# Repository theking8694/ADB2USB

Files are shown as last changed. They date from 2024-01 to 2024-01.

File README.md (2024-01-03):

# ADB2USB
An Apple ADB to USB adapter for QMK using the ATMega32U2, featuring USB-C!
One of the projects I used as an intro to KiCad

Probably not the simplest, but follows what is said for the 32U2 datasheet.

Tested working, highly suggest a 32U2 with DFU bootloader flashed (DigiKey seems to have them preflashed)
Highly reccomend using hot air instead of an iron.

You can use the online QMK configurator firmware builder to produce a .hex that can be flashed using QMK Toolbox (Arduino will not see the DFU bootloader!)
(Or compile it locally and flash it however you want)

The CSV contains a BOM listing generated by KiCad,
parts I used are listed below:

GRM0335C1E200JA01D (20pF cap), 

CL05A105MQ5NNNC (1uF cap), 

USB4085-GF-A (USB C port), 

RMCF0805FT1K00 (1k resistor), 

WR06X220 JTL (22 resistor), 

ABLS-16.000MHZ-D-3-Y-T (16Mhz crystal), 

M50-3530342 (optinal ISP headers), 

PTS526 SM15 SMTR2 LFS (reset switch), 

RR0816P-512-D (5.1k resistor), 

WR06X103 JTL (10k resistor), 

CUI_MD-40SMK (S-video socket) (yes, S-video),

and, of course, an ATMega32U2(-A)

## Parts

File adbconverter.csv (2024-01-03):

Component Count: | 16
Ref | Qnty | Value | Cmp name | Footprint | Description | Vendor | DNP
C1, C2 | 2 | 20pF | C | Capacitor_SMD:C_0201_0603Metric_Pad0.64x0.40mm_HandSolder | Unpolarized capacitor
C3, C4 | 2 | 1uF | C | Capacitor_SMD:C_0402_1005Metric_Pad0.74x0.62mm_HandSolder | Unpolarized capacitor
J1 | 1 | AVR-ISP-6 | AVR-ISP-6 | Connector_PinHeader_1.27mm:PinHeader_2x03_P1.27mm_Vertical | Atmel 6-pin ISP connector
J2 | 1 | DIN-4 | MD-40SMK | adbconverter:CUI_MD-40SMK
P1 | 1 | USB C Receptacle 3.0 | USB_C_Receptacle_USB2.0 | Connector_USB:USB_C_Receptacle_GCT_USB4085 | USB 2.0-only Type-C Receptacle connector
R1, R2 | 2 | 5.1k | R_US | Resistor_SMD:R_0603_1608Metric_Pad0.98x0.95mm_HandSolder | Resistor, US symbol
R3 | 1 | 10k | R_US | Resistor_SMD:R_0603_1608Metric_Pad0.98x0.95mm_HandSolder | Resistor, US symbol
R_ADB1 | 1 | 1k | R_US | Resistor_SMD:R_0805_2012Metric_Pad1.20x1.40mm_HandSolder | Resistor, US symbol
R_D+1 | 1 | 22 | R_US | Resistor_SMD:R_0603_1608Metric_Pad0.98x0.95mm_HandSolder | Resistor, US symbol
R_D-1 | 1 | 22 | R_US | Resistor_SMD:R_0603_1608Metric_Pad0.98x0.95mm_HandSolder | Resistor, US symbol
SW1 | 1 | RESET | SW_Push | Button_Switch_SMD:SW_SPST_SKQG_WithStem | Push button switch, generic, two pins
U1 | 1 | ATmega32U2-A | ATmega32U2-A | Package_QFP:TQFP-32_7x7mm_P0.8mm | 16MHz, 32kB Flash, 1kB SRAM, 1kB EEPROM, TQFP-32
Y1 | 1 | Crystal | Crystal | Crystal:Crystal_SMD_HC49-SD | Two pin crystal

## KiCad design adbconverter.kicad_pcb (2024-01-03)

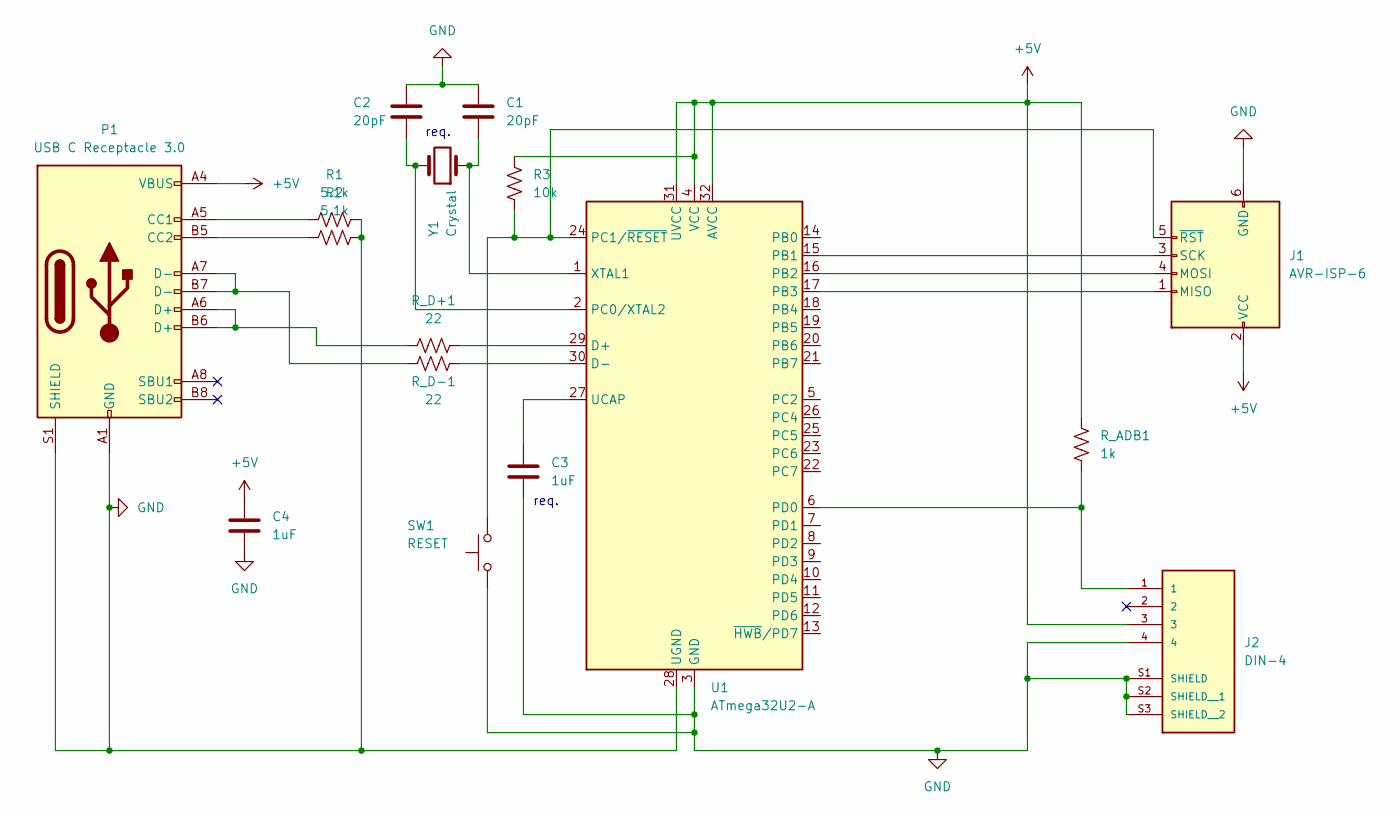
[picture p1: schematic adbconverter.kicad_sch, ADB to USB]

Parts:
C1, C2: 20pF; C_0201_0603Metric_Pad0.64x0.40mm_HandSolder
C3, C4: 1uF; C_0402_1005Metric_Pad0.74x0.62mm_HandSolder
J1: AVR-ISP-6; PinHeader_2x03_P1.27mm_Vertical
J2: DIN-4; CUI_MD-40SMK; PART_REV 1.02
P1: USB C Receptacle 3.0; USB_C_Receptacle_GCT_USB4085
R1, R2: 5.1k; R_0603_1608Metric_Pad0.98x0.95mm_HandSolder
R3: 10k; R_0603_1608Metric_Pad0.98x0.95mm_HandSolder
R_ADB1: 1k; R_0805_2012Metric_Pad1.20x1.40mm_HandSolder
R_D+1: 22; R_0603_1608Metric_Pad0.98x0.95mm_HandSolder
R_D-1: 22; R_0603_1608Metric_Pad0.98x0.95mm_HandSolder
SW1: RESET; SW_SPST_SKQG_WithStem
U1: ATmega32U2-A; TQFP-32_7x7mm_P0.8mm
Y1: Crystal; Crystal_SMD_HC49-SD

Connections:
+5V: C4.2, J1.2 (VCC), J2.3, P1.A4 (VBUS), P1.A9 (VBUS), P1.B4 (VBUS), P1.B9 (VBUS), R3.2, R_ADB1.2, U1.4 (VCC), U1.31 (UVCC), U1.32 (AVCC)
GND: C1.2, C2.2, C3.1, C4.1, J1.6 (GND), J2.4, J2.S1 (SHIELD), J2.S2 (SHIELD__1), J2.S3 (SHIELD__2), P1.A1 (GND), P1.A12 (GND), P1.B1 (GND), P1.B12 (GND), P1.S1 (SHIELD), R1.2, R2.2, SW1.1, U1.3 (GND), U1.28 (UGND)
unnamed: J1.1 (MISO), U1.17 (PB3)
unnamed: J1.4 (MOSI), U1.16 (PB2)
unnamed: J1.3 (SCK), U1.15 (PB1)
unnamed: J1.5 (~RST), R3.1, SW1.2, U1.24 (PC1/~RESET)
unnamed: P1.A5 (CC1), R1.1
unnamed: P1.B5 (CC2), R2.1
unnamed: P1.A6 (D+), P1.B6 (D+), R_D+1.1
unnamed: P1.A7 (D-), P1.B7 (D-), R_D-1.1
unnamed: R_D+1.2, U1.29 (D+)
unnamed: R_D-1.2, U1.30 (D-)
unnamed: C2.1, U1.2 (PC0/XTAL2), Y1.2
unnamed: J2.1, R_ADB1.1, U1.6 (PD0)
unnamed: C3.2, U1.27 (UCAP)
unnamed: C1.1, U1.1 (XTAL1), Y1.1

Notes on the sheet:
req.

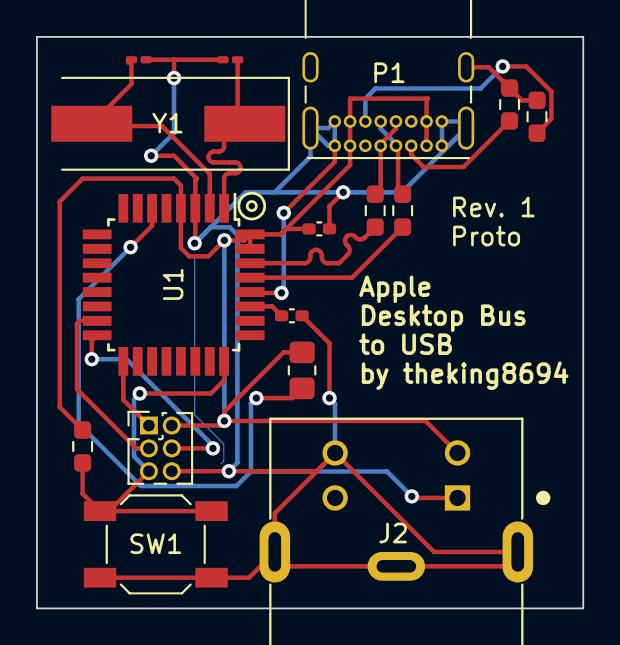
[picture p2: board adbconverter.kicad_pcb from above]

Board: 2 copper layers, 30.4 x 31.8 mm, 16 parts (0 on the bottom side), 16 nets.
